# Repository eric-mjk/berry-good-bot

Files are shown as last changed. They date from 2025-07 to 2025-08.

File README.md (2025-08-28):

# Berry Good Bot 🍓🤖

딸기 수확을 위한 자율 로봇 시스템 - SCARA 타입 로봇과 시각 서보잉 기술을 결합한 정밀 과일 수확 로봇

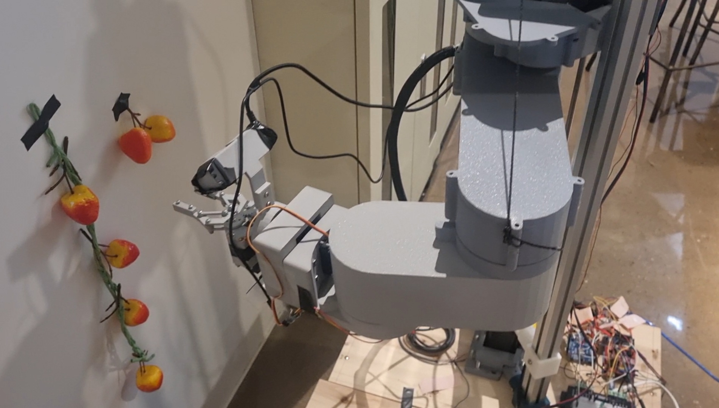
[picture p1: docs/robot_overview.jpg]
Berry Good Bot


-----

## 🌟 프로젝트 개요

본 프로젝트는 2025년 서울대학교 창의설계축전 출품작으로, 2025년 6월부터 8월까지 개발되었습니다. 

Berry Good Bot은 ROS2 Humble 기반의 자율 딸기 수확 로봇으로, SCARA 형태의 5축 로봇 팔과 이중 카메라 시스템을 활용하여 딸기를 정밀하게 수확할 수 있습니다. 시각 서보잉(Visual Servoing) 기술과 Behavior Tree를 통한 체계적인 작업 계획을 통해 안정적이고 효율적인 과일 수확을 실현합니다.

### 주요 특징
- **SCARA 로봇 구조**: Linear Joint(스크류) + 3개의 평면 회전 Joint + Wrist Joint + Gripper
- **이중 카메라 시스템**: RGBD 카메라(RealSense D435i) + RGB 카메라를 활용한 robust한 인식
- **하이브리드 시각 서보잉**: PBVS(Position-Based) + IBVS(Image-Based) 결합
- **모듈화된 아키텍처**: ROS2 Action Server 기반의 확장 가능한 구조
- **Behavior Tree**: 복잡한 작업 시퀀스와 오류 처리를 위한 체계적 접근
-----

## 🏗️ 시스템 아키텍처

### 하드웨어 구성
- **제어 컴퓨터**: NVIDIA Jetson Orin Nano (8GB) + JetPack 6.2
- **로봇 제어**: Arduino UNO (Linear, Wrist, Gripper) + Arduino MEGA (Joint 1,2,3)
- **카메라**: Intel RealSense D435i (상단) + RGB 카메라 (하단)
- **액추에이터**: NEMA17 스텝모터 4개 + MG996R 서보모터 2개

### 소프트웨어 구성

#### 1. 시리얼 통신 브리지 (`berry_serial_bridge`)
- Jetson Orin Nano와 Arduino 간의 시리얼 통신 관리
- 스텝모터의 각가속도/각속도 제어로 진동 최소화
- Homing 동작을 통한 절대 위치 초기화

#### 2. 로봇 모델링 (`berrybot_description`)
- URDF 기반 로봇 모델 정의
- RViz2를 통한 실시간 시각화 및 동기화
- CAD 파일 기반 정확한 기구학 모델링

#### 3. 운동학 제어 (`berry_kinematics_control`)
세 가지 제어 인터페이스 제공:
- **Named Pose**: 미리 정의된 자세(ready, basket, home)로 이동
- **Inverse Kinematics**: IKPY 라이브러리 기반 3차원 위치/자세 제어
- **Servo Twist**: Jacobian 기반 실시간 속도 제어 (Robotics Toolbox 활용)

#### 4. 인식 시스템 (`berry_perception`)

**Rough Approach용 인식**:
- YOLO 기반 딸기 검출 및 confidence 기반 선택
- RGBD 데이터의 outlier 제거 및 depth 평균화
- 3차원 접근점 계산 및 EEF 자세 결정

**Visual Servoing용 인식**:
- RGBD + RGB 카메라의 Ray intersection을 통한 줄기 위치 추정
- HSV 기반 색상 필터링과 YOLO 결과의 IOU 매칭
- Gripper ROI 내 타겟 검증으로 정확도 향상

#### 5. 시각 서보잉 (`berry_perception/visualServoing`)
- **IBVS (Image-Based Visual Servoing)**: RGB 카메라의 image feature error 기반 제어
- **PBVS (Position-Based Visual Servoing)**: 3차원 공간상의 위치 error 기반 제어
- **Hybrid Approach**: IBVS + PBVS twist 조합으로 robust한 서보잉

#### 6. 작업 계획 (Behavior Tree)
- BehaviorTree.CPP 기반 작업 시퀀스 관리
- Hydra를 통한 설정 파일 관리 및 모듈화
- Fallback과 Retry 메커니즘으로 안정성 확보
-----

## 📦 설치 방법

### 개발 환경
- Ubuntu 22.04 (Jetson Orin Nano JetPack 6.2)
- ROS2 Humble
- Python 3.10

### 필수 의존성 설치

1. **ROS2 Humble 설치**
   ```bash
   # ROS2 Humble 설치 가이드 참조
   # https://docs.ros.org/en/humble/Installation/Ubuntu-Install-Debians.html
   ```

2. **BehaviorTree.CPP v3 설치**
   ```bash
   # BehaviorTree.CPP 공식 튜토리얼 참조
   # https://www.behaviortree.dev/docs/intro
   ```

3. **MoveIt2 설치** (현재 빌드 의존성으로 필요, 추후 의존성 제거 예정) 
   ```bash
   # MoveIt2 공식 튜토리얼 참조
   # https://moveit.ai/install-moveit2/source/
   ```

### 설치 및 빌드

1.  ROS2 워크스페이스를 생성하고 `src` 디렉토리로 이동합니다.

    ```bash
    mkdir -p berryGoodBot_ws/src
    cd berryGoodBot_ws/src
    ```

2.  소스 코드를 클론합니다.

    ```bash
    git clone https://github.com/sawo0150/berry-good-bot.git
    ```

3.  워크스페이스 루트로 돌아가서 빌드합니다.

    ```bash
    cd ..
    colcon build
    ```

4.  빌드가 완료되면 터미널에 워크스페이스를 소싱합니다.

    ```bash
    source install/setup.bash
    ```

-----

## ▶️ 실행 방법

프로젝트는 여러 개의 독립적인 ROS2 Action Server와 이를 호출하는 Behavior Tree 클라이언트로 구성됩니다.

### 1\. 핵심 서비스(Action Servers) 실행

각각의 서비스를 위해 **새로운 터미널**을 열고 아래 명령어를 실행하세요. (실행 전 `source install/setup.bash` 필수)

  - **터미널 1: 제어 및 시리얼 브리지 실행**
    이 Lauch 파일은 로봇 모델(URDF)을 RViz2에 띄우고, Jetson과 아두이노 간의 시리얼 통신을 담당하는 `bridge_node`를 실행합니다.

    ```bash
    ros2 launch berry_serial_bridge testkinematicsControl.launch.py
    ```

  - **터미널 2: 인식 시스템 실행**
    이 Launch 파일은 RealSense 카메라 드라이버, 딸기 위치를 3D로 추정하는 `perception_node`, 그리고 근접 서보잉을 위한 `visualServoing` 노드를 실행합니다.

    ```bash
    ros2 launch berry_perception perception_bringup.launch.py
    ```

### 2\. 행동 트리(Behavior Tree) 실행

위의 서버들이 모두 실행된 상태에서, **또 다른 새 터미널**을 열고 아래 명령어를 실행하여 로봇의 실제 동작을 시작합니다.

1.  프로젝트의 루트 디렉토리로 이동합니다.

    ```bash
    cd berryGoodBot_ws/src/berry-good-bot
    ```

2.  `run_bt.py` 스크립트를 실행합니다.

    ```bash
    python3 scripts/run_bt.py
    ```

#### 동작 시나리오 변경

`run_bt.py`는 **Hydra** 프레임워크를 사용하여 설정을 관리합니다. 실행할 Behavior Tree 시나리오를 변경하려면 `config/default.yaml` 파일을 수정하세요.

```yaml
# config/default.yaml
defaults:
  - _self_
  - bt: pick_with_loops   # 이 부분을 변경하여 시나리오 선택
  - robot: fake
  - env: sim
```

`bt` 항목에 원하는 YAML 파일 이름을 지정할 수 있습니다.

  - `berry_named_pose_test1`: 예약된 자세(`ready`, `home` 등)로 이동하는 테스트.
  - `rough_approach_test2`: 딸기 인식 후 거친 접근만 테스트.
  - `roughApproach_with_ibvs2`: 거친 접근 후 시각 서보잉까지 수행하여 딸기를 수확하고, 종류(딸기, 오렌지, 사과)에 따라 다른 바구니에 분류.
  - `pick_with_loops`: 필드에 있는 모든 과일을 안정적으로 수확할 때까지 작업을 반복하는 최종 버전.

-----
## 🎥 작동 영상

| 로봇 구동 영상 |
| :---: |
| 로봇 작동 영상 |

| RViz2 및 제어 화면 |
| :---: |
| RViz 및 터미널 화면 녹화 |

-----

## 🧑‍💻 제작자 정보

  - **권태영**: 로봇 하드웨어 설계 및 제작
  - **김민준**: YOLO-Pose 딥러닝 모델 개발
  - **박상원**: 시스템 통합 및 제어 소프트웨어 개발

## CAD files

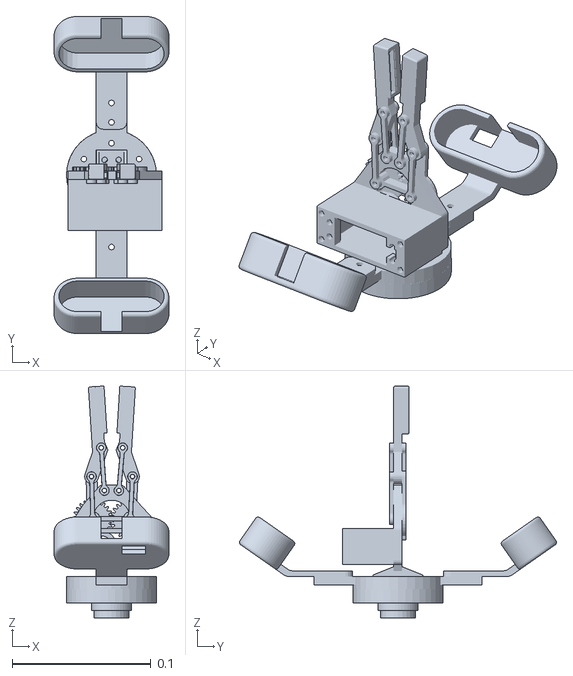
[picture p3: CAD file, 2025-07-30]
robot/berrybot_description/meshes/link5.STL
0.083 x 0.229 x 0.167

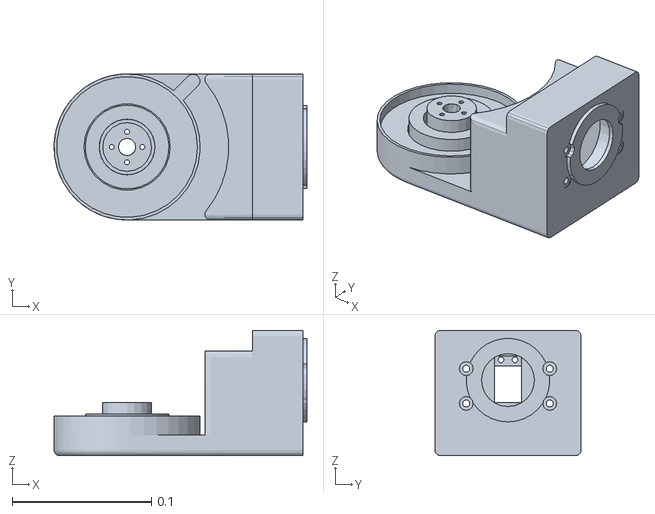
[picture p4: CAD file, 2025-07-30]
robot/berrybot_description/meshes/link4.STL
0.182 x 0.105 x 0.09

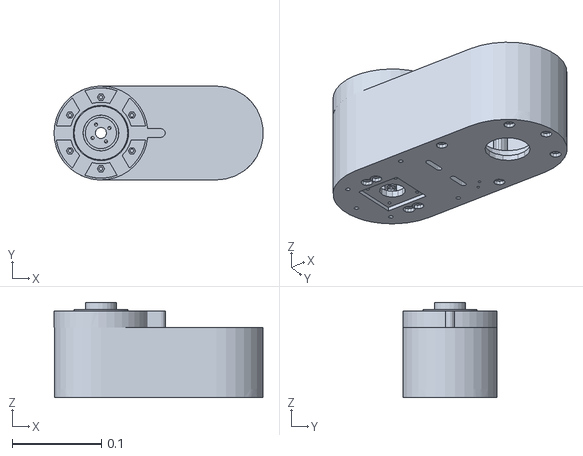
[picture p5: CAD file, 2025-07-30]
robot/berrybot_description/meshes/link3.STL
0.234 x 0.105 x 0.107

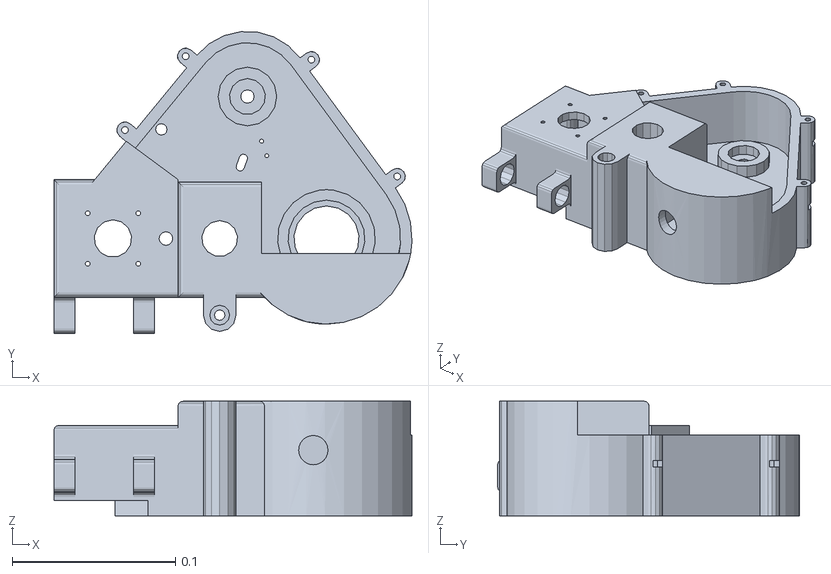
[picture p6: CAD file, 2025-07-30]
robot/berrybot_description/meshes/link1.STL
0.22 x 0.185 x 0.0703

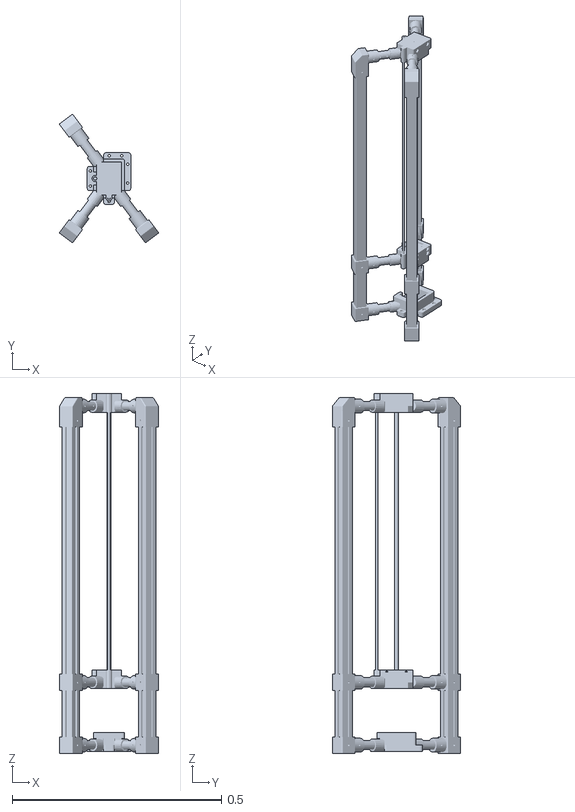
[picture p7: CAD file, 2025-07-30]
robot/berrybot_description/meshes/base_link.STL
0.236 x 0.306 x 0.86

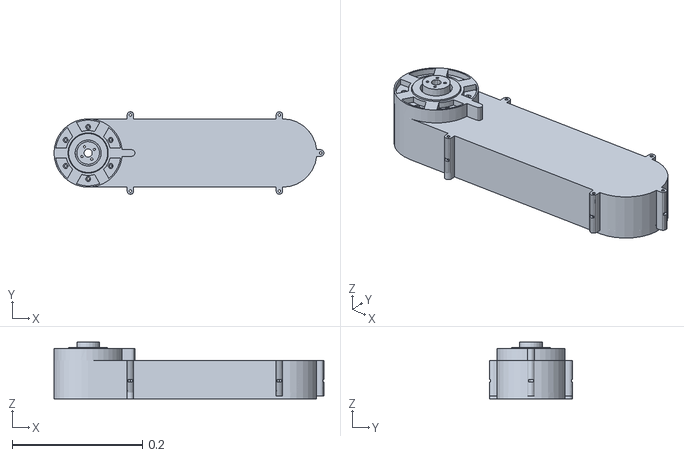
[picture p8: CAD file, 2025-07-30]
robot/berrybot_description/meshes/link2.STL
0.415 x 0.127 x 0.087

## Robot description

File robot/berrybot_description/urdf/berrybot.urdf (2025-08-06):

<?xml version="1.0" encoding="utf-8"?>
<!-- This URDF was automatically created by SolidWorks to URDF Exporter! Originally created by Stephen Brawner (brawner@gmail.com) 
     Commit Version: 1.6.0-4-g7f85cfe  Build Version: 1.6.7995.38578
     For more information, please see http://wiki.ros.org/sw_urdf_exporter -->
<robot name="berrybot">
  <link name="base_link">
    <inertial>
      <origin xyz="-0.0260796634761501 -0.0365555163799671 0.396735421162825" rpy="0 0 0" />
      <mass value="2.87702129673757" />
      <inertia ixx="0.0857296623482647" ixy="4.29743171459672E-05" ixz="-8.56295018331263E-06" iyy="0.0853945250064593" iyz="-2.94665863351021E-06" izz="0.00153624654266533" />
    </inertial>
    <visual>
      <origin xyz="0 0 0" rpy="0 0 0" />
      <geometry>
        <mesh filename="package://berrybot_description/meshes/base_link.STL" />
      </geometry>
      <material name="">
        <color rgba="0.792156862745098 0.819607843137255 0.933333333333333 1" />
      </material>
    </visual>
    <collision>
      <origin xyz="0 0 0" rpy="0 0 0" />
      <geometry>
        <mesh filename="package://berrybot_description/meshes/base_link.STL" />
      </geometry>
    </collision>
  </link>
  <link name="link1">
    <inertial>
      <origin xyz="0.0120728344115199 0.0142112009609397 -0.0329840674201771" rpy="0 0 0" />
      <mass value="0.641607816803253" />
      <inertia ixx="0.00176349377389527" ixy="6.23322864568198E-05" ixz="4.24931676487362E-05" iyy="0.00226935278556233" iyz="0.00022001578901826" izz="0.00343231312876168" />
    </inertial>
    <visual>
      <origin xyz="0 0 0" rpy="0 0 0" />
      <geometry>
        <mesh filename="package://berrybot_description/meshes/link1.STL" />
      </geometry>
      <material name="">
        <color rgba="0.792156862745098 0.819607843137255 0.933333333333333 1" />
      </material>
    </visual>
    <collision>
      <origin xyz="0 0 0" rpy="0 0 0" />
      <geometry>
        <mesh filename="package://berrybot_description/meshes/link1.STL" />
      </geometry>
    </collision>
  </link>
  <joint name="joint1" type="prismatic">
    <origin xyz="-0.0043164 -0.0057205 0.3368" rpy="0 0 0" />
    <parent link="base_link" />
    <child link="link1" />
    <axis xyz="0 0 -1" />
    <limit lower="-0.600" upper="-0.01" effort="300" velocity="0.02" />
  </joint>
  <link name="link2">
    <inertial>
      <origin xyz="0.132648108588069 -7.66258727355126E-06 -0.0337313487070523" rpy="0 0 0" />
      <mass value="1.21790808347326" />
      <inertia ixx="0.00154846196743339" ixy="-1.54219095761203E-07" ixz="-1.90382758622812E-05" iyy="0.00425206110802368" iyz="6.02386696555079E-08" izz="0.00545645010060873" />
    </inertial>
    <visual>
      <origin xyz="0 0 0" rpy="0 0 0" />
      <geometry>
        <mesh filename="package://berrybot_description/meshes/link2.STL" />
      </geometry>
      <material name="">
        <color rgba="0.792156862745098 0.819607843137255 0.933333333333333 1" />
      </material>
    </visual>
    <collision>
      <origin xyz="0 0 0" rpy="0 0 0" />
      <geometry>
        <mesh filename="package://berrybot_description/meshes/link2.STL" />
      </geometry>
    </collision>
  </link>
  <joint name="joint2" type="revolute">
    <origin xyz="0.0638586161135005 0 -0.07355" rpy="0 0 0" />
    <parent link="link1" />
    <child link="link2" />
    <axis xyz="0 0 -1" />
    <limit lower="-2.015854" upper="0.253071" effort="200" velocity="3" />
  </joint>
  <link name="link3">
    <inertial>
      <origin xyz="0.0546872133827593 -2.39582301345131E-07 -0.0388851599914216" rpy="0 0 0" />
      <mass value="0.783047855038987" />
      <inertia ixx="0.0010727699197224" ixy="-1.53993150086213E-07" ixz="-2.11974954258733E-05" iyy="0.00325810821857342" iyz="-3.42858217553346E-08" izz="0.00389666351584499" />
    </inertial>
    <visual>
      <origin xyz="0 0 0" rpy="0 0 0" />
      <geometry>
        <mesh filename="package://berrybot_description/meshes/link3.STL" />
      </geometry>
      <material name="">
        <color rgba="0.792156862745098 0.819607843137255 0.933333333333333 1" />
      </material>
    </visual>
    <collision>
      <origin xyz="0 0 0" rpy="0 0 0" />
      <geometry>
        <mesh filename="package://berrybot_description/meshes/link3.STL" />
      </geometry>
    </collision>
  </link>
  <joint name="joint3" type="revolute">
    <origin xyz="0.299 0 -0.079" rpy="0 0 0" />
    <parent link="link2" />
    <child link="link3" />
    <axis xyz="0 0 -1" />
    <limit lower="-1.879718" upper="2.483602" effort="200" velocity="3" />
  </joint>
  <link name="link4">
    <inertial>
      <origin xyz="0.0628613382563859 0.000167411794933691 0.00149049884660379" rpy="0 0 0" />
      <mass value="0.651212854430719" />
      <inertia ixx="0.00102423931258213" ixy="-6.24775124143484E-07" ixz="-0.000157050299577248" iyy="0.00105611984337837" iyz="3.71821724595456E-08" izz="0.00139084360081601" />
    </inertial>
    <visual>
      <origin xyz="0 0 0" rpy="0 0 0" />
      <geometry>
        <mesh filename="package://berrybot_description/meshes/link4.STL" />
      </geometry>
      <material name="">
        <color rgba="0.792156862745098 0.819607843137255 0.933333333333333 1" />
      </material>
    </visual>
    <collision>
      <origin xyz="0 0 0" rpy="0 0 0" />
      <geometry>
        <mesh filename="package://berrybot_description/meshes/link4.STL" />
      </geometry>
    </collision>
  </link>
  <joint name="joint4" type="revolute">
    <origin xyz="0.1306413838865 0 -0.08945" rpy="0 0 0" />
    <parent link="link3" />
    <child link="link4" />
    <axis xyz="0 0 1" />
    <limit lower="-1.719148" upper="1.771508" effort="200" velocity="3" />
  </joint>
  <link name="link5">
    <inertial>
      <origin xyz="0.00045711 -0.0025199 0.02899" rpy="0 0 0" />
      <mass value="0.17785" />
      <inertia ixx="7.2572E-05" ixy="-4.8839E-07" ixz="-5.9379E-08" iyy="8.4772E-05" iyz="-2.6021E-07" izz="0.00011467" />
    </inertial>
    <visual>
      <origin xyz="0 0 0" rpy="0 0 0" />
      <geometry>
        <mesh filename="package://berrybot_description/meshes/link5.STL" />
      </geometry>
      <material name="">
        <color rgba="0.79216 0.81961 0.93333 1" />
      </material>
    </visual>
    <collision>
      <origin xyz="0 0 0" rpy="0 0 0" />
      <geometry>
        <mesh filename="package://berrybot_description/meshes/link5.STL" />
      </geometry>
    </collision>
  </link>
  <joint name="joint5" type="revolute">
    <origin xyz="0.1397 0 0.0257499999999998" rpy="1.5707963267949 0 1.5707963267949" />
    <parent link="link4" />
    <child link="link5" />
    <axis xyz="0 0 1" />
    <limit lower="-1.570796" upper="1.570796" effort="200" velocity="3" />
  </joint>
</robot>

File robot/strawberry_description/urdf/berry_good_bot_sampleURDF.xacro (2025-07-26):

<?xml version="1.0"?>
<robot xmlns:xacro="http://www.ros.org/wiki/xacro" name="berry_good_bot">

  <!-- ===== 파라미터 ===== -->
  <xacro:property name="link_radius" value="0.05"/>   <!-- 0.02 ▶ 0.05 m -->
  <xacro:property name="L1" value="0.25"/>
  <xacro:property name="L2" value="0.20"/>
  <xacro:property name="L3" value="0.15"/>

  <!-- ===== 간단 원통 링크 (축 = +X) ===== -->
  <xacro:macro name="cyl_link" params="name length radius">
    <link name="${name}">
      <!-- ◀ 원통 중심을 +X 쪽으로, 축을 X에 맞춰 Y축(+90°) 회전 -->
      <inertial>
        <origin xyz="${length/2} 0 0" rpy="0 1.57079632679 0"/>
        <mass value="0.4"/>
        <inertia ixx="0.002" iyy="0.002" izz="0.001" ixy="0" ixz="0" iyz="0"/>
      </inertial>
      <visual>
        <origin xyz="${length/2} 0 0" rpy="0 1.57079632679 0"/>
        <geometry><cylinder length="${length}" radius="${radius}"/></geometry>
        <material name="Cyan"><color rgba="0 1 1 1"/></material>
      </visual>
      <collision>
        <origin xyz="${length/2} 0 0" rpy="0 1.57079632679 0"/>
        <geometry><cylinder length="${length}" radius="${radius}"/></geometry>
      </collision>
    </link>
  </xacro:macro>

  <!-- ===== 링크 & 조인트 체인 ===== -->
  <link name="base_link"/>

  <!-- Z축 선형 스크류 -->
  <link name="screw_link"/>
  <joint name="screw_joint" type="prismatic">
    <parent link="base_link"/>
    <child link="screw_link"/>
    <origin xyz="0 0 0" rpy="0 0 0"/>
    <axis xyz="0 0 1"/>
    <limit lower="0.0" upper="1.0" velocity="0.3" effort="100.0"/>
  </joint>

  <!-- 3-DOF 팔 -->
  <xacro:cyl_link name="link1" length="${L1}" radius="${link_radius}"/>
  <joint name="joint1" type="revolute">
    <parent link="screw_link"/>
    <child link="link1"/>
    <origin xyz="0 0 0" rpy="0 0 0"/>
    <axis xyz="0 0 1"/>
    <limit lower="-${pi}" upper="${pi}" velocity="1.5" effort="50.0"/>
  </joint>

  <xacro:cyl_link name="link2" length="${L2}" radius="${link_radius}"/>
  <joint name="joint2" type="revolute">
    <parent link="link1"/>
    <child link="link2"/>
    <origin xyz="${L1} 0 0" rpy="0 0 0"/>
    <axis xyz="0 0 1"/>
    <limit lower="-${pi}" upper="${pi}" velocity="1.5" effort="40.0"/>
  </joint>

  <xacro:cyl_link name="link3" length="${L3}" radius="${link_radius}"/>
  <joint name="joint3" type="revolute">
    <parent link="link2"/>
    <child link="link3"/>
    <origin xyz="${L2} 0 0" rpy="0 0 0"/>
    <axis xyz="0 0 1"/>
    <limit lower="-${pi}" upper="${pi}" velocity="2.0" effort="30.0"/>
  </joint>

  <!-- EEF 축 회전 -->
  <link name="wrist_link"/>
  <joint name="wrist_roll_joint" type="revolute">
    <parent link="link3"/>
    <child link="wrist_link"/>
    <origin xyz="${L3} 0 0" rpy="0 0 0"/>
    <axis xyz="1 0 0"/>
    <limit lower="-3.141592653589793" upper="3.141592653589793" effort="10.0" velocity="2.5"/>
  </joint>

  <!-- 그리퍼 -->
  <link name="gripper_base"/>
  <joint name="gripper_joint" type="prismatic">
    <parent link="wrist_link"/>
    <child link="gripper_base"/>
    <origin xyz="0 0 0" rpy="0 0 0"/>
    <axis xyz="0 1 0"/>
    <limit lower="0.0" upper="0.04" velocity="0.02" effort="20.0"/>
  </joint>

  <!-- 작업 좌표계 -->
  <link name="tool0"/>
  <joint name="tool0_fixed" type="fixed">
    <parent link="gripper_base"/>
    <child link="tool0"/>
    <origin xyz="0 0 0.05" rpy="0 0 0"/>
  </joint>

</robot>

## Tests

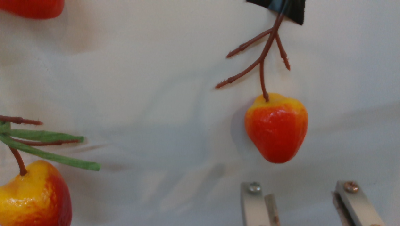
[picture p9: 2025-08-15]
berry_perception/testCode/TOP_RGBD_RAW_screenshot_13.08.2025.png

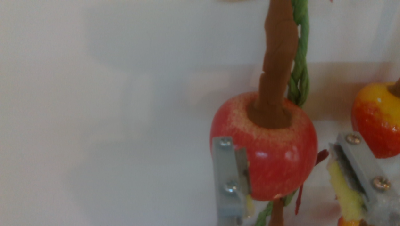
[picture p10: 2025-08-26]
berry_perception/testCode/TOP_RGBD_RAW_screenshot_26.08.2025.png

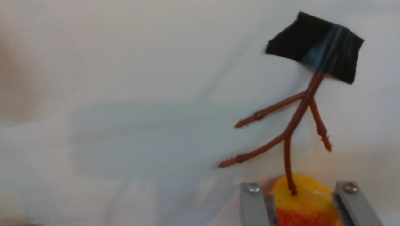
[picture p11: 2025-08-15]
berry_perception/testCode/TOP_RGBD_RAW_screenshot_13.98.2025.png

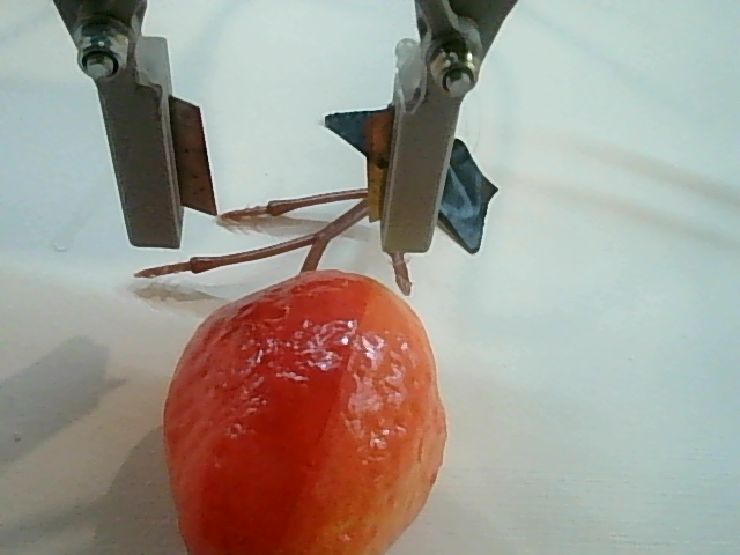
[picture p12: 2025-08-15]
berry_perception/testCode/BOTTOM_RGB_RAW_screenshot_13.08.2025.PNG

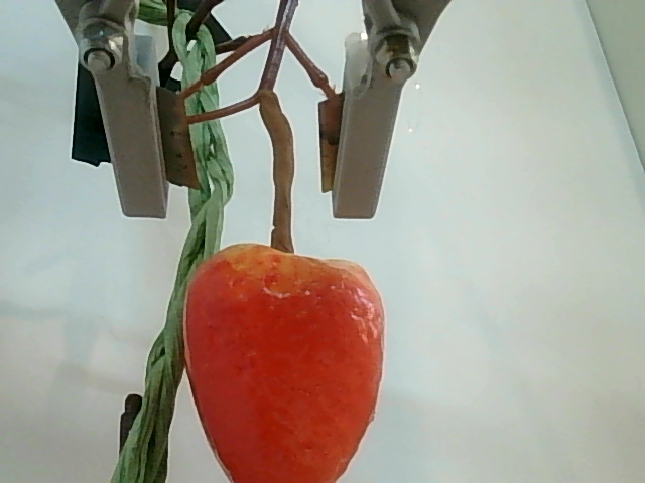
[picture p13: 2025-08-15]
berry_perception/testCode/BOTTOM_RGB_RAW_screenshot_15.08.2025.png

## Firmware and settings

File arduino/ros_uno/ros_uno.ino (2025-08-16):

#include <Arduino.h>
#include <Servo.h>

/* ────── 하드웨어 핀 ────── */
#define DIR_PIN     9   // 스텝퍼 DIR
#define STEP_PIN    6   // 스텝퍼 STEP
#define LIMIT_PIN   7   // 리밋 스위치 (눌리면 LOW)

const int wristServoPin  = 11;
const int gripServoPin   = 3;

/* ────── 스텝퍼 모션 파라미터 ────── */
const float STEPS_PER_REV = 2415.0;   // 한 회전 스텝
const float SCREW_LEAD_MM = 4.0;      // 한 회전 이동(mm)
const float STEPS_PER_MM  = STEPS_PER_REV / SCREW_LEAD_MM;

const float MAX_VEL_STEP_PER_S   = 160000.0;   // ★조정: 최대 속도(스텝/s)
const float MAX_ACCEL_STEP_PER_S2 = 80000.0;  // ★조정: 최대 가속(스텝/s²)

/* ────── 루프당 최대 스텝 수 ────── */
volatile uint8_t maxStepsPerLoop = 4;   // ★조정: updateStepper() 1회 호출 시 최대 스텝 펄스 수

/* ────── 서보 파라미터 ────── */
const int  ANGLE_GRIPPER_OPEN   = 170;
const int  ANGLE_GRIPPER_CLOSED = 65;
const float MAX_SERVO_DEG_PER_SEC = 180.0;  // ★조정: 서보 속도 한계

/* ────── 런타임 상태 ────── */
volatile long  curStepPos = 0;   // 절대 위치(스텝)
volatile long  targetStepPos = 0;

float   curStepVel  = 0;         // 현재 속도(스텝/s)
unsigned long lastStepTimeUs = 0; // 마지막 스텝 발생 시각

Servo wristServo, gripServo;
volatile float curWristDeg = 0;      // -90~90°
volatile float targetWristDeg = 0;

volatile bool  curGripOpen = false;
volatile bool  targetGripOpen = false;

/* ────── 통신 출력 타이머 ────── */
const unsigned long STATUS_INTERVAL_MS = 500;
unsigned long lastStatusMs = 0;

/* ────── 수신 버퍼 (비블로킹 파싱용) ────── */
char recvBuf[32];
uint8_t recvPos = 0;

/* ───────────────────────────────────────────────────────────── */
/*                        기본 함수 선언                         */
void homeAxis();
void processSerial();
void updateStepper();
void updateServos();
void sendStatus();

/* ───────────────────────────────────────────────────────────── */
void setup() {
  /* 핀 초기화 */
  pinMode(DIR_PIN, OUTPUT);
  pinMode(STEP_PIN, OUTPUT);
  pinMode(LIMIT_PIN, INPUT_PULLUP);

  digitalWrite(DIR_PIN, LOW);
  digitalWrite(STEP_PIN, LOW);

  Serial.begin(115200);
  while (!Serial) {}

  /* 서보 초기화 */
  wristServo.attach(wristServoPin);
  gripServo.attach(gripServoPin);

  /* Homing */
  homeAxis();

  /* 초기 서보 위치 */
  curWristDeg = targetWristDeg = 0;
  wristServo.write(90);               // 중앙
  curGripOpen = targetGripOpen = false;
  gripServo.write(ANGLE_GRIPPER_CLOSED);

  Serial.println(F("\n=== 명령 형식: \"Z_mm W_deg G(0/1)\" ==="));
  Serial.println(F("   예) -120.0  30  1"));
  Serial.println(F("----------------------------------------"));
}

void loop() {
  processSerial();   // (1) 새 명령 수신
  updateStepper();   // (2) 스텝퍼 한-스텝/가속도 관리
  updateServos();    // (3) 서보 각도 점진 이동
  sendStatus();      // (4) 주기적 상태 전송
}

/* ───────────────────────────────────────────────────────────── */
/*                     1) 시리얼 명령 처리                       */
// void processSerial() {
//   if (!Serial.available()) return;

//   // String line = Serial.readStringUntil('\n');
//   // line.trim();
//   // if (line.length() == 0) return;

//   // // 공백 구분자 세 개 값 기대
//   // float zMm=0, wDeg=0;
//   // int   gCmd=0;
//   // int n = sscanf(line.c_str(), "%f %f %d", &zMm, &wDeg, &gCmd);
//   // if (n != 3) {
//   //   Serial.print(F("❌ 잘못된 입력: ")); Serial.println(line); Serial.println(n);
//   //   return;
//   // }
  
//   String line = Serial.readStringUntil('\n');
//   line.trim();
//   if (line.length() == 0) return;

//   // 공백 구분자로 세 개 값 분리
//   int sep1 = line.indexOf(' ');
//   int sep2 = line.indexOf(' ', sep1 + 1);
//   if (sep1 == -1 || sep2 == -1) {
//     Serial.print(F("❌ 잘못된 입력: "));
//     Serial.println(line);
//     return;
//   }
//   float zMm = line.substring(0, sep1).toFloat();
//   float wDeg = line.substring(sep1 + 1, sep2).toFloat();
//   int   gCmd = line.substring(sep2 + 1).toInt();

//   /* Z 축 범위 체크 */
//   if (zMm > 0 || zMm < -590) {
//     Serial.println(F("⚠️ Z 범위(0 ~ -590 mm) 초과"));
//   } else {
//     targetStepPos = lround(zMm * STEPS_PER_MM);
//   }

//   /* 손목 범위 체크 */
//   if (wDeg < -90 || wDeg > 90) {
//     Serial.println(F("⚠️ W 범위(-90 ~ 90°) 초과"));
//   } else {
//     targetWristDeg = wDeg;
//   }

//   /* 그리퍼 */
//   targetGripOpen = (gCmd == 1);

//   // Serial.print(F("🆗 목표 → Z:")); Serial.print(zMm,1);
//   // Serial.print(F("mm  W:"));      Serial.print(wDeg,0);
//   // Serial.print(F("°  G:"));       Serial.println(targetGripOpen?1:0);
// }

void processSerial() {
  // 시리얼 버퍼에 데이터가 있으면 한 글자씩 읽어 처리
  while (Serial.available()) {
    // // ▶ 디버그: 읽은 문자 출력
    // char dbgChar = Serial.peek();
    // Serial.print(F("[DBG] Serial.peek(): '"));
    // Serial.print(dbgChar);
    // Serial.println(F("'"));

    char c = Serial.read();
    // 'a' 문자를 명령 종료자로 사용 (또는 버퍼 풀 시)
    if (c == 'a' || recvPos >= sizeof(recvBuf) - 1) {
      recvBuf[recvPos] = '\0';           // 문자열 종료
      // // ▶ 디버그: 완성된 버퍼 내용 출력
      // Serial.print(F("[DBG] Complete recvBuf: \""));
      // Serial.print(recvBuf);
      // Serial.println(F("\""));

      // 빈 줄 무시
      if (recvPos > 0) {
        // 공백으로 세 토큰 분리
        // // ▶ 디버그: 토큰 분리 전 원본 버퍼 복사
        // char tmpBuf[32];
        // strcpy(tmpBuf, recvBuf);
        // Serial.print(F("[DBG] Tokenizing tmpBuf: \""));
        // Serial.print(tmpBuf);
        // Serial.println(F("\""));

        char *p1 = strtok(recvBuf, " ");
        char *p2 = strtok(NULL, " ");
        char *p3 = strtok(NULL, " ");
        // // ▶ 디버그: 파싱된 토큰 출력
        // Serial.print(F("[DBG] p1=\"")); Serial.print(p1); Serial.println(F("\""));
        // Serial.print(F("[DBG] p2=\"")); Serial.print(p2); Serial.println(F("\""));
        // Serial.print(F("[DBG] p3=\"")); Serial.print(p3); Serial.println(F("\""));

        if (!p1 || !p2 || !p3) {
          Serial.print(F("❌ 잘못된 입력: "));
          Serial.println(recvBuf);
        } else {
          float zMm = atof(p1);
          float wDeg = atof(p2);
          int   gCmd = atoi(p3);
          // Z 축 범위 체크
          if (zMm > 0 || zMm < -590) {
            Serial.println(F("⚠️ Z 범위(0 ~ -590 mm) 초과"));
          } else {
            targetStepPos = lround(zMm * STEPS_PER_MM);
          }
          // 손목 범위 체크
          if (wDeg < -90 || wDeg > 90) {
            Serial.println(F("⚠️ W 범위(-90 ~ 90°) 초과"));
          } else {
            targetWristDeg = wDeg;
          }
          // 그리퍼
          targetGripOpen = (gCmd == 1);
        }
      }
      recvPos = 0;                       // 버퍼 리셋
    } else if (c >= 32 && c != 'a') {   // 'a'는 저장하지 않음
      // // ▶ 디버그: 버퍼에 추가될 문자 출력
      // Serial.print(F("[DBG] Appending to recvBuf: '"));
      // Serial.print(c);
      // Serial.println(F("'"));

      recvBuf[recvPos++] = c;           // 가시문자만 저장
    }
    
  }
}

/* ───────────────────────────────────────────────────────────── */
/*                     2) 스텝퍼 업데이트                         */
void updateStepper() {
  long   delta = targetStepPos - curStepPos;
  // if (delta == 0 && curStepVel == 0) return;          // 정지 상태
  if (delta == 0) {
    curStepVel = 0;                                  // 완전 정지
    return;
  }

  /* 이동 방향 & 목표 속도 */
  int dirSign = (delta > 0) ? 1 : -1;
  float desiredVel = dirSign * MAX_VEL_STEP_PER_S;
  // Serial.print(targetStepPos);
  // Serial.print(curStepPos);
  // Serial.println(dirSign);

  /* 가속도 제한으로 속도 업데이트 */
  unsigned long nowUs = micros();
  float dt = (nowUs - lastStepTimeUs) / 1e6;          // s
  if (dt == 0) dt = 1e-6;
  if (curStepVel < desiredVel) {
    curStepVel += MAX_ACCEL_STEP_PER_S2 * dt;
    if (curStepVel > desiredVel) curStepVel = desiredVel;
  } else if (curStepVel > desiredVel) {
    curStepVel -= MAX_ACCEL_STEP_PER_S2 * dt;
    if (curStepVel < desiredVel) curStepVel = desiredVel;
  }

  /* 마지막 단계에서 감속(목표까지 남은 거리 대비) */
  float reqBrakingDist = (curStepVel*curStepVel) / (2*MAX_ACCEL_STEP_PER_S2);
  if (abs(delta) < reqBrakingDist) {
    desiredVel = dirSign * sqrt(2 * MAX_ACCEL_STEP_PER_S2 * abs(delta));
    if (curStepVel > desiredVel)
      curStepVel -= MAX_ACCEL_STEP_PER_S2 * dt;
  }

  /* 스텝 펄스 타이밍 계산 */
  float stepIntervalUsF = 1e6 / abs(curStepVel);
  static float intervalCarry = 0;  // 소수 누적
  unsigned long stepIntervalUs = (unsigned long)(stepIntervalUsF + intervalCarry);
  intervalCarry = (stepIntervalUsF + intervalCarry) - stepIntervalUs; // 잔여

  if (abs(curStepVel) < 1) return;  // 아직 너무 느려 스텝 안찍음

  // if (nowUs - lastStepTimeUs >= stepIntervalUs) {
  //   /* 리밋 스위치 보호 */
  //   if (digitalRead(LIMIT_PIN) == HIGH && dirSign > 0) { // 아래쪽으로 더 가면 안 됨
  //     curStepVel = 0;
  //     targetStepPos = curStepPos;      // 목표도 여기로
  //     Serial.println(F("⚠️ 리밋 스위치 감지 → Z 정지"));
  //     return;
  //   }

  //   /* DIR 설정 */
  //   digitalWrite(DIR_PIN, (dirSign > 0) ? HIGH : LOW);

  //   /* 펄스 출력 */
  //   digitalWrite(STEP_PIN, HIGH);
  //   delayMicroseconds(50);
  //   digitalWrite(STEP_PIN, LOW);

  //   curStepPos += dirSign;
  //   lastStepTimeUs = nowUs;
  // }
  /* 한 번의 호출에서 여러 스텝을 처리 */
  uint8_t stepsMade = 0;
  while ((nowUs - lastStepTimeUs) >= stepIntervalUs &&
         stepsMade < maxStepsPerLoop &&
         curStepPos != targetStepPos) {

    long deltaLoop = targetStepPos - curStepPos;
    int dirLoop = (deltaLoop > 0) ? 1 : -1;

    /* 리밋 스위치 보호 */
    if (digitalRead(LIMIT_PIN) == HIGH && dirLoop > 0) { // 아래쪽으로 더 가면 안 됨
      curStepVel = 0;
      targetStepPos = curStepPos;      // 목표도 여기로
      Serial.println(F("⚠️ 리밋 스위치 감지 → Z 정지"));
      break;
    }

    /* DIR 설정 */
    digitalWrite(DIR_PIN, (dirLoop > 0) ? HIGH : LOW);

    /* 펄스 출력 */
    digitalWrite(STEP_PIN, HIGH);
    delayMicroseconds(50);
    digitalWrite(STEP_PIN, LOW);

    curStepPos += dirLoop;
    lastStepTimeUs += stepIntervalUs;   // 다음 스텝 기준 시각
    stepsMade++;
  }

}

/* ───────────────────────────────────────────────────────────── */
/*                     3) 서보 업데이트                           */
void updateServos() {
  /* 손목 */
  if (curWristDeg != targetWristDeg) {
    float dt = (millis() - lastStatusMs) / 1000.0;      // rough loop dt
    if (dt == 0) dt = 0.001;
    float step = MAX_SERVO_DEG_PER_SEC * dt;
    if (abs(targetWristDeg - curWristDeg) < step)
      curWristDeg = targetWristDeg;
    else
      curWristDeg += (targetWristDeg > curWristDeg ? step : -step);

    int servoVal = constrain(lround(curWristDeg + 90), 0, 180);
    wristServo.write(servoVal);
  }

  /* 그리퍼 */
  if (curGripOpen != targetGripOpen) {
    curGripOpen = targetGripOpen;
    gripServo.write(curGripOpen ? ANGLE_GRIPPER_OPEN
                                : ANGLE_GRIPPER_CLOSED);
  }
}

/* ───────────────────────────────────────────────────────────── */
/*                     4) 상태 메시지 전송                        */
void sendStatus() {
  unsigned long nowMs = millis();
  if (nowMs - lastStatusMs < STATUS_INTERVAL_MS) return;
  lastStatusMs = nowMs;

  float zmm = curStepPos / STEPS_PER_MM;
  Serial.print(F("POS Z:")); Serial.print(zmm,1);
  Serial.print(F(" W:"));    Serial.print(curWristDeg,0);
  Serial.print(F(" G:"));    Serial.println(curGripOpen?1:0);
}

/* ───────────────────────────────────────────────────────────── */
/*                         Homing 함수                           */
void homeAxis() {
  Serial.println(F(">>> Homing 시작"));
  digitalWrite(DIR_PIN, HIGH);    // 스위치 방향(위쪽)으로
  delay(100);

  while (digitalRead(LIMIT_PIN) == LOW) {     // LOW면 아직 미감지
    digitalWrite(STEP_PIN, HIGH);
    delayMicroseconds(50);
    digitalWrite(STEP_PIN, LOW);
    delayMicroseconds(50);
  }

  curStepPos = targetStepPos = 0;
  curStepVel = 0;
  Serial.println(F(">>> 리밋 스위치 감지 → 원점 설정"));
  
  /* 스위치에서 10 mm 이탈 */
  digitalWrite(DIR_PIN, LOW);
  for (long i=0;i< (long)(100*STEPS_PER_MM); i++) {
    digitalWrite(STEP_PIN, HIGH);
    delayMicroseconds(50);
    digitalWrite(STEP_PIN, LOW);
    delayMicroseconds(50);
    curStepPos--;
  }
  targetStepPos = curStepPos;
  Serial.println(F(">>> Homing 완료"));
}

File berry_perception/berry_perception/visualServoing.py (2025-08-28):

#!/usr/bin/env python3
# berry_perception/visualServoing.py
"""
IBVSBottomServo (업데이트)
 - 상단 RGBD + 하단 RGB 동시 사용
 - 목표:
    (A) 하단: bbox 중심 x == gripper ROI 중심 x  → 카메라 z축 회전(wz)만 유지
    (B) 상단 y2 키포인트와 하단 y1 키포인트가 같은 물리점이라 가정.
        **삼각측량은 RGBD(상단) 카메라의 ray 위**에서만 수행(깊이만 추정) → 타깃 3D 포인트 계산
    (C) gripper tip(link5 원점에서 z축 +0.13m)이 그 포인트와 일치하도록 선속도 제어
        └ 우선 z축 정렬(|ez|>tol_z 이면 vz만), 이후 xy 정렬(vx,vy)
 - 제어:
    - 선속도: vx, vy, vz (base_link frame)
    - 각속도: wz (bbox x 정렬), wx=0, wy=0  ← 각도 서보 삭제
 - 프레임 변환:
    bottom_camera_link / camera_link (body)  ←(고정)→ optical
    base_link ← cam_link(들)  … TF로 조회
 - ServoTwist 액션으로 servo 모드 진입 후 /eef_twist_cmd 에 Twist 퍼블리시
"""
import os, time, math
import numpy as np, cv2, torch, rclpy
from rclpy.node import Node
from rclpy.action import ActionClient, ActionServer, GoalResponse, CancelResponse
from rclpy.callback_groups import ReentrantCallbackGroup
from geometry_msgs.msg import Twist, Point
from sensor_msgs.msg import Image, CameraInfo
from visualization_msgs.msg import Marker
from cv_bridge import CvBridge
from tf2_ros import Buffer, TransformListener
import tf_transformations as tft
from ultralytics import YOLO
from ament_index_python.packages import get_package_share_directory

from berry_interface.action import ServoTwist, VisualServoing

# stem_and_yolo: 기존 로직 그대로 사용
from .stem_and_yolo import (
    select_yolo_by_roi_similarity, paint_polygons_with_hsv, get_bottom_mask_polygons,
    BOTTOM_MASK_ENABLE, BOTTOM_MASK_HSV, BOTTOM_MASK_FEATHER
)
# 헬퍼 모듈 (새로 추가)
from .ibvs_helpers import (
    R_LINK_FROM_OPT, xywh_to_xyxy, saturate, quat_to_R, boxes_conf_kpts,
    pixel_to_ray_opt, point_on_ray1_closest_to_ray2, draw_kpts,
    lookup_Rt_base_from_link, omega_base_from_omega_cam, publish_marker
)

class IBVSBottomServo(Node):
    def __init__(self):
        super().__init__(
            "ibvs_bottom_servo",
            automatically_declare_parameters_from_overrides=True
        )
        self.log = self.get_logger()
        self.bridge = CvBridge()

        # ───── 파라미터 ───────────────────────────────────────────
        # 콜백 그룹(재진입 허용): action, timer, subs 모두 같은 그룹으로 묶어 경합 방지
        self.cb_grp = ReentrantCallbackGroup()

        # 액션 서버 이름
        self.declare_parameter("visual_servo_action_name", "visual_servoing")
        # 액션 진행 중이 아닐 때는 제어 루프가 publish 하지 않도록 게이팅
        self._vs_active: bool = False
        self._vs_cancel_requested: bool = False
        self._vs_deadline: float = -1.0
 
        # 카메라 내부 파라미터 (기본값 = 네가 준 값)
        self.declare_parameter("fx", 636.235)
        self.declare_parameter("fy", 619.641)
        self.declare_parameter("cx", 211.89)
        self.declare_parameter("cy", 221.05)
 
        # 상단 RGBD 토픽
        self.declare_parameter("top_rgb_topic",   "/camera/camera/color/image_raw")
        self.declare_parameter("top_depth_topic", "/camera/camera/aligned_depth_to_color/image_raw")
        self.declare_parameter("top_info_topic",  "/camera/camera/color/camera_info")
        self.declare_parameter("top_grip_roi_xywh", [498,250, 180, 228])

        # 프레임 이름
        self.declare_parameter("base_frame", "base_link")
        self.declare_parameter("eef_frame",  "link5")
        self.declare_parameter("cam_frame",  "bottom_camera_link")   # bottom 카메라 body frame
        self.declare_parameter("top_cam_frame", "camera_link")       # top RGBD body frame
 
        # 하단 카메라 입력
        self.declare_parameter("use_v4l", True)
        self.declare_parameter("v4l_index", 0)
        self.declare_parameter("bottom_rgb_topic", "/bottom_cam/image_raw")

        # YOLO
        self.declare_parameter("yolo_model_rel", "model/model3.pt")
        self.declare_parameter("yolo_conf", 0.01)
        self.declare_parameter("yolo_sim_conf_thresh", 0.30)  # (IoU + conf) 점수 임계값

        # Gripper ROI (bbox x-align 기준)
        self.declare_parameter("grip_roi_xywh", [63, 83, 360, 471])

        # 제어 게인/제약
        # ▷ 제어/추론 주기 분리
        self.declare_parameter("ctrl_rate_hz", 10.0)     # 제어 루프 Hz (기본 3)
        self.declare_parameter("yolo_rate_hz", 3.0)     # YOLO 추론 Hz (기본 제어와 동일, 독립 조절)

        # 각속도 (wz) 게인
        self.declare_parameter("K_wz_center", 0.8)     # (u_err/fx)(rad) → wz_cam
        self.declare_parameter("w_limit", 0.5)         # 각속도 절대 최대 [rad/s]
        # 선속도 게인/제약
        self.declare_parameter("K_vx", 1.5)
        self.declare_parameter("K_vy", 1.5)
        self.declare_parameter("K_vz", 1.5)
        self.declare_parameter("v_limit", 0.2)        # [m/s]
        self.declare_parameter("tip_offset_z", 0.135)   # link5 z축 +0.13m
        self.declare_parameter("tol_z", 0.02)          # [m]  z 게이트 임계
        self.declare_parameter("tol_xy", 0.02)         # [m]  xy 종료 임계
 


        self.declare_parameter("ang_tol_deg", 2.0)     # [deg]   종료 기준
        self.declare_parameter("ux_tol_px",   4.0)     # [px]    종료 기준
        self.declare_parameter("steady_count_req", 8)  # 조건 만족 프레임 누적

        # Debug 창
        self.declare_parameter("show_debug", True)
        # 디버깅 옵션
        self.declare_parameter("debug_triangulation", False)
        self.declare_parameter("rviz_show_rays", True)

        # 타깃 오프셋(베이스 좌표계 +Z, m)
        self.declare_parameter("target_offset_z_base", 0.02)

        # ───── 상태 변수 ───────────────────────────────────────────
        self.fx = float(self.get_parameter("fx").value)
        self.fy = float(self.get_parameter("fy").value)
        self.cx = float(self.get_parameter("cx").value)
        self.cy = float(self.get_parameter("cy").value)

        self.base_frame = self.get_parameter("base_frame").value
        self.eef_frame  = self.get_parameter("eef_frame").value
        self.cam_frame  = self.get_parameter("cam_frame").value
        self.top_cam_frame = self.get_parameter("top_cam_frame").value

        self.grip_roi = [int(v) for v in self.get_parameter("grip_roi_xywh").value]
        self.top_grip_roi = [int(v) for v in self.get_parameter("top_grip_roi_xywh").value]
 
        # 카메라 입력 (VideoCapture 또는 토픽)
        self.cap = None
        self.bot_img = None
        if bool(self.get_parameter("use_v4l").value):
            idx = int(self.get_parameter("v4l_index").value)
            self.cap = cv2.VideoCapture(idx)
            if not self.cap.isOpened():
                self.log.error(f"[camera] cannot open VideoCapture index {idx}")
                self.cap = None
        else:
            topic = self.get_parameter("bottom_rgb_topic").value
            self.sub_bot = self.create_subscription(Image, topic, self.cb_bottom_rgb, 10)
 
        # 상단 RGBD 구독
        self.top_rgb  = None
        self.top_depth = None
        self.top_info  = None
        self.create_subscription(Image, self.get_parameter("top_rgb_topic").value,   self._cb_top_rgb,   10)
        self.create_subscription(Image, self.get_parameter("top_depth_topic").value, self._cb_top_depth, 10)
        self.create_subscription(CameraInfo, self.get_parameter("top_info_topic").value, self._cb_top_info, 10)
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

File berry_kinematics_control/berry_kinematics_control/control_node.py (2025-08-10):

# berry_kinematics_control/control_node.py
import rclpy, numpy as np, time, threading
from rclpy.action import ActionServer, CancelResponse, GoalResponse
from rclpy.node   import Node
from sensor_msgs.msg   import JointState
from geometry_msgs.msg import PoseStamped, TransformStamped, Twist
from berry_interface.action import MoveToNamedPose, MoveToPose, ServoTwist

from .kin_utils import build_models, load_named_poses, damped_pinv, lspb_interpolate

class BerryControl(Node):

    def __init__(self):
        super().__init__("berry_control")

        # ---------------- 파라미터 ----------------
        # self.declare_parameter("urdf_path")
        # self.declare_parameter("pose_yaml")
        self.declare_parameter("urdf_path", "")
        self.declare_parameter("pose_yaml", "")
        urdf_path  = self.get_parameter("urdf_path").get_parameter_value().string_value
        pose_yaml  = self.get_parameter("pose_yaml").get_parameter_value().string_value

        self.robot, self.ik_chain, self.joint_names = build_models(urdf_path)
        self.named_poses = load_named_poses(pose_yaml)
        self.n_joints = len(self.joint_names)
        # self.current_q = np.zeros(self.n_joints)

        self.n_joints = len(self.joint_names)

        # ① YAML 에 home 이 있으면 그 값을 첫 상태로 사용
        if "home" in self.named_poses:
            home = np.asarray(self.named_poses["home"], dtype=float)
            self.current_q = np.pad(home, (0, self.n_joints - len(home)), "constant")
        else:
            self.current_q = np.zeros(self.n_joints)   # fallback

        # ── 관절 한계 (origin 제외) ─────────────────────────
        self.q_bounds = np.array([lnk.bounds            # shape = (n, 2)
                                  for lnk in self.ik_chain.links[1:]])

        # joint_state 퍼블리셔
        self.js_pub = self.create_publisher(JointState, "/joint_states", 10)
        self.joint_state_msg = JointState(name=self.joint_names)

        # 🔹 최초 1회 & 주기적으로 현재 값 송신 -----------------------
        self.publish_joint_state()               # 한 번 찍고
        self.idle_timer = self.create_timer(0.05,  # 20 Hz
                                            self.publish_joint_state)
        # 액션 서버 3종
        self.named_srv = ActionServer(
            self, MoveToNamedPose, "move_to_named_pose",
            execute_callback=self.exec_named)

        self.pose_srv = ActionServer(
            self, MoveToPose, "move_to_pose",
            execute_callback=self.exec_pose)

        self.servo_srv = ActionServer(
            self, ServoTwist, "servo_twist",
            execute_callback=self.exec_servo,
            goal_callback=self.servo_goal_cb,
            cancel_callback=self.servo_cancel_cb)

        # servo 모드 변수
        self.servo_active = False
        self._servo_busy  = False          # goal 수락 여부 제어
        self._servo_canceled = False       # 이번 goal이 취소됐는지 플래그
        self.latest_twist = np.zeros(6)
        self.twist_sub = self.create_subscription(
            Twist, "/eef_twist_cmd", self.twist_cb, 10)

        # servo 루프 타이머 (250 Hz)
        self.servo_timer = self.create_timer(0.04, self.servo_loop)

    # ---------- 공통 퍼블리시 ----------
    def publish_joint_state(self):
        self.joint_state_msg.header.stamp = self.get_clock().now().to_msg()
        self.joint_state_msg.position = self.current_q.tolist()
        self.js_pub.publish(self.joint_state_msg)
        self.get_logger().debug(f"publish_joint_state → q = {np.round(self.current_q,3).tolist()}")

    # ---------- Twist 콜백 ----------
    def twist_cb(self, msg: Twist):
        self.latest_twist = np.array([
            msg.linear.x, msg.linear.y, msg.linear.z,
            msg.angular.x, msg.angular.y, msg.angular.z])

    # ---------- NamedPose ----------
    async def exec_named(self, goal_handle):
        pose_name = goal_handle.request.pose_name

        # self.get_logger().info(f"[exec_named] 요청받음 → `{pose_name}`")+        
        t0 = time.time()
        self.get_logger().info(f"[exec_named] ▶ START  pose=`{pose_name}`")

        if pose_name not in self.named_poses:
            goal_handle.abort()
            return MoveToNamedPose.Result(success=False,
                                          message="Unknown pose",
                                          )

        # target_q = np.asarray(self.named_poses[pose_name], dtype=float)
        target_q = np.asarray(self.named_poses[pose_name], dtype=float)
        # YAML 관절 개수가 실제보다 적으면 나머지는 현재 값 유지
        if target_q.size < self.n_joints:
            pad = self.current_q[target_q.size : self.n_joints]
            target_q = np.concatenate([target_q, pad])
        # 많으면 잘라내기
        elif target_q.size > self.n_joints:
            target_q = target_q[: self.n_joints]
        n_steps = 100
        for i, q in enumerate(lspb_interpolate(self.current_q, target_q, n_steps)):
            self.current_q = q
            self.publish_joint_state()
            fb = MoveToNamedPose.Feedback(progress=i/float(n_steps))
            goal_handle.publish_feedback(fb)
            time.sleep(0.06)                 # 10 ms 블로킹 (멀티스레드 Executor라 OK)
 
        err = float(np.linalg.norm(self.current_q - target_q))
        dt  = time.time() - t0
        self.get_logger().info(
            f"[exec_named] ✔ DONE  pose=`{pose_name}`  steps={n_steps}  "
            f"final_err={err:.6f}  elapsed={dt:.2f}s")

        goal_handle.succeed()
        return MoveToNamedPose.Result(success=True, message="Reached")

    # ---------- MoveToPose ----------
    async def exec_pose(self, goal_handle):
        target = goal_handle.request.target_pose

        # self.get_logger().info(f"[exec_pose] 요청받음 → pos=({target.pose.position.x:.3f},"
        t0 = time.time()
        self.get_logger().info(f"[exec_pose] ▶ START  pos=({target.pose.position.x:.3f},"
                               f"{target.pose.position.y:.3f},{target.pose.position.z:.3f}), "
                               "ori=(%.2f,%.2f,%.2f,%.2f)" % (
                                 target.pose.orientation.w,
                                 target.pose.orientation.x,
                                 target.pose.orientation.y,
                                 target.pose.orientation.z))

        # T = self.pose_to_matrix(target)
        # # ik_sol = self.ik_chain.inverse_kinematics(T, initial_position=np.r_[self.current_q, 0.0])
        
        # # ─── 여기가 핵심 ───
        # # IKPy 체인이 기대하는 길이만큼 0으로 패딩한 뒤
        # # 앞쪽 self.n_joints 칸에 current_q를 채웁니다.
        # mask     = self.ik_chain.active_links_mask     # 길이 8
        # init_q   = np.zeros(len(mask))                 # ✅ 8
        # self.get_logger().info(f"[exec_pose] len(mask) → ({len(mask)}")

        # j = 0
        # for i, active in enumerate(mask):
        #     if active:
        #         init_q[i] = self.current_q[j]
        #         j += 1

        # ik_sol = self.ik_chain.inverse_kinematics_frame(
        #     T,
        #     initial_position=init_q)
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

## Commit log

2025-07-13 Fix XML (& → &amp;) in strawberry_core/package.xml
2025-07-13 폴더 구조 푸시
2025-07-13 github action 삭제
2025-07-13 robotArm sample xacro visualization 확인
    [berry_good_bot_sampleURDF.xacro]
2025-07-13 sample moveit description file 생성 완료
    [berry_good_bot.ros2_control.xacro, berry_good_bot.urdf.xacro, berry_good_bot_sampleURDF.xacro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]
2025-07-17 BT 기반 모듈화 ws 틀잡기
2025-07-17 output 정리
2025-07-19 모듈화 구조 디버깅 완료
2025-07-20 BT 구조 디버깅 완료 & rough 접근 디버깅중
2025-07-24 일단 구조 디버깅중...
    [berry_servo_config.yaml]
2025-07-26 berry_kinematics control 개발중
    [berry_good_bot_sampleURDF.xacro]
2025-07-30 실제 urdf, move to named pose 디버깅 완료
    [base_link.STL, berrybot.urdf, link1.STL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]
2025-07-30 servoing interface 개발 완료
2025-08-03 jetson orin nano 디버깅
2025-08-03 arduino 코드 디버깅
2025-08-05 robot Arduino 컨트롤 update
2025-08-05 uno mega test 코드 최종 완성
2025-08-06 ROS - arduino 연결 완료 (joint publisher)
    [berrybot.urdf]
2025-08-07 kinematics control 디버깅중...
2025-08-07 link - rgbd 연결 완료
2025-08-08 perceptio module 적용 완료 + offset 적용 방식 수정
    [bridge_node.py, debug_cli.py]
2025-08-10 behavior tree namedtoPose 연동 작업 디버깅 완료
2025-08-10 일단 rough aproach까지 완료...
2025-08-11 실시간 perception (visual servoing 용) 디버깅 중...
2025-08-15 visual servoing Test 완료
2025-08-15 visual servoing 디버깅 완료!! 딸기 딸 수 있다!!
2025-08-22 yolo 데이터 모으기 코드 commit
2025-08-22 data 캡쳐 디버깅
2025-08-26 딸기, 오렌지, 사과 분류 picking 성공!!
2025-08-27 Readme 수정
2025-08-28 수확 과정 살짝 수정
    [visualServoing.py]
